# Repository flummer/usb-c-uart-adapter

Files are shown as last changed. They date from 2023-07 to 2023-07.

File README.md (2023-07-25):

# USB-C to TTL-Serial adapter with CP210x

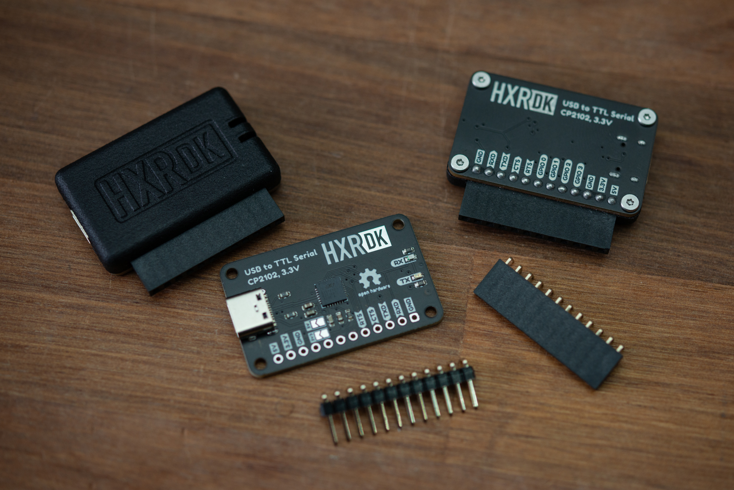
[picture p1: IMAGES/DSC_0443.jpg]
Adapters


This is just a simpel adapter with USB-C and TTL level UART, plus a few extra IO's. The pinout is designed to fit the 2022 Supercon/2023 Hackaday Berlin badges, and if you want to use the power rails, you need to bridge the corresponsing solder jumpers, they are disconneected by standard and need to be disconnected if used with the badges, as these to pins are used for other things on the badge.

## License

The contents of this repository is released under the following license:

* the "Creative Commons Attribution-ShareAlike 4.0 International License"
  (CC BY-SA 4.0) full text of this license is included in the LICENSE file
  and a copy can also be found at
  [http://creativecommons.org/licenses/by-sa/4.0/](http://creativecommons.org/licenses/by-sa/4.0/)

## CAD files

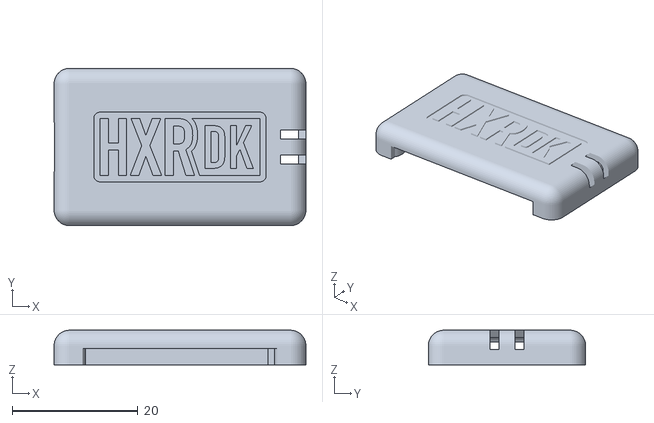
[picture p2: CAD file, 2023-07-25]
case/case.stl
40.0 x 25.0 x 5.50

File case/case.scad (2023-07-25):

/* Case for USB-C to TTL Serial Adapter
 *
 * Design: @thomasflummer
 *
 * License: CC-BY-SA
 *
 */

module case(pcb_length, pcb_width, height, corner_radius)
{
    union()
    {
        difference()
        {
            union()
            {
                hull()
                {
                    for (x = [-1, 1])
                    {
                        for (y = [-1, 1])
                        {
                            translate([x*(pcb_length/2 - corner_radius), y*(pcb_width/2 - corner_radius), (height - corner_radius)/2])
                                cylinder(h = height - corner_radius, r = corner_radius, center = true, $fn = 50);

                            translate([x*(pcb_length/2 - corner_radius), y*(pcb_width/2 - corner_radius), (height - corner_radius)])
                                sphere(r = corner_radius, $fn = 50);
                        }
                    }
                }
            }
            union()
            {
                // main cutout
                hull()
                {
                    for (x = [-1, 1])
                    {
                        for (y = [-1, 1])
                        {
                            translate([x*(pcb_length/2 - corner_radius), y*(pcb_width/2 - corner_radius), (height - corner_radius)/2])
                                cylinder(h = height - corner_radius + 0.01, r = corner_radius - 1.2, center = true, $fn = 50);

                            translate([x*(pcb_length/2 - corner_radius), y*(pcb_width/2 - corner_radius), (height - corner_radius)])
                                sphere(r = corner_radius - 1.2, $fn = 50);
                        }
                    }
                }

                // USB connector cutout
                translate([-pcb_length/2, 0, 3.6/2])
                rotate(90, [0, 0, 1])
                rotate(90, [1, 0, 0])
                    hull()
                    {
                        for (x = [-1, 1])
                        {
                            for (y = [-1, 1])
                            {
                                translate([x*(9.4/2 - 1.5), y*(3.6/2 - 1.5), 0])
                                    cylinder(h = 10, r = 1.5, center = true, $fn = 50);
                            }
                        }
                    }

                translate([-pcb_length/2+10/2-0.2, 0, 0])
                    cube([10, 9.4, 3.6], center = true);

                // Activity LEDs
                
                translate([pcb_length/2-6, 2, 0])
                rotate(45, [0, 1, 0])
                    cube([5, 1.4, 20], center = true);

                translate([pcb_length/2-6, -2, 0])
                rotate(45, [0, 1, 0])
                    cube([5, 1.4, 20], center = true);

                // 12 pin female header
                translate([0, -pcb_width/2, 2.54/2])
                    cube([12*2.54+0.4, 5, 2.54+0.1], center = true);
                
                    
                // logo on the inside (for clear transparent)
                // translate([0, 0, height-3.3])
                // logo on the outside (for non-clear)
                translate([0, 0, height+2.5-0.3])
                linear_extrude(height = 5, center = true, scale=1)
                    import(file = "logo_simple.svg", center = true, dpi = 200);

                for (x = [-1, 1])
                {
                    for (y = [-1, 1])
                    {
                        translate([x*((pcb_length)/2 - corner_radius), y*((pcb_width)/2 - corner_radius), (height-1.2)/2])
                            cylinder(h = height-1.2, r = 1.5, center = true, $fn = 50);
                    }
                }
            }
        }
        difference()
        {
            intersection()
            {
                union()
                {
                    // main cutout
                    hull()
                    {
                        for (x = [-1, 1])
                        {
                            for (y = [-1, 1])
                            {
                                translate([x*(pcb_length/2 - corner_radius), y*(pcb_width/2 - corner_radius), (height - corner_radius)/2])
                                    cylinder(h = height - corner_radius + 0.01, r = corner_radius - 1, center = true, $fn = 50);

                                translate([x*(pcb_length/2 - corner_radius), y*(pcb_width/2 - corner_radius), (height - corner_radius)])
                                    sphere(r = corner_radius - 1, $fn = 50);
                            }
                        }
                    }
                }
                union()
                {
                    for (x = [-1, 1])
                    {
                        for (y = [-1, 1])
                        {
                            translate([x*((pcb_length)/2 - corner_radius), y*((pcb_width)/2 - corner_radius), (height)/2])
                                cylinder(h = height, r = corner_radius, center = true, $fn = 50);
                        }
                    }
                    
                    translate([pcb_length/2-6/2, 0, height/2])
                        cube([6, 1.2, height], center = true);
                }
            }
            union()
            {
                for (x = [-1, 1])
                {
                    for (y = [-1, 1])
                    {
                        translate([x*((pcb_length)/2 - corner_radius), y*((pcb_width)/2 - corner_radius), (height - 1.2)/2])
                            cylinder(h = height - 1.2 + 0.01, r = 1.5, center = true, $fn = 50);
                    }
                }
            }
        }
    }
}

module light_guide()
{
    difference()
    {
        union()
        {
            translate([-2.5, 0, -2.5])
            rotate(90, [1, 0, 0])
                cylinder(h = 2.5, r = 2.5, center = true, $fn = 50);
            
            translate([-2.5 - 2.5/2, 0, -2.5])
                cube([2.5, 2.5, 5], center = true);

            translate([-2.5, 0, -2.5 - 2.5/2])
                cube([5, 2.5, 2.5], center = true);
        }
        union()
        {
            translate([-2.5, 0, -2.5*2 - 3/2 + 0.8])
                cube([5.01, 2.51, 3], center = true);

            difference()
            {
                union()
                {
                    translate([-2.5, 0, -2.5])
                        cube([6, 6, 6], center = true);
                }
                union()
                {
                    translate([-2.5, 0, -2.5])
                    rotate(90, [1, 0, 0])
                        cylinder(h = 7, r = 2.5 - 1.2, center = true, $fn = 50);
                    
                    translate([-2.5 - 3/2, 0, -2.5-1.2])
                        cube([3, 2.5, 5], center = true);

                    translate([-2.5-1.2, 0, -2.5 - 3/2])
                        cube([5, 2.5, 3], center = true);                

                    translate([-6, 0, -5.5])
                    rotate(45, [0, 1, 0])
                        cube([5-0.2, 1.4-0.2, 20], center = true);
                
                }
            }
        }        
    }
}

case(40, 25, 5.5, 2.5);

//light_guide();

/*
translate([40/2, 2, 5.5])
    color("#eeeeee")
    light_guide();

translate([40/2, -2, 5.5])
    color("#eeeeee")
    light_guide();
*/

/*
difference()
{
    case(40, 25, 5.5, 2.5);
    translate([0, -25-(25/2)+2.5, 0])
        cube([50, 50, 50], center = true);
}
*/

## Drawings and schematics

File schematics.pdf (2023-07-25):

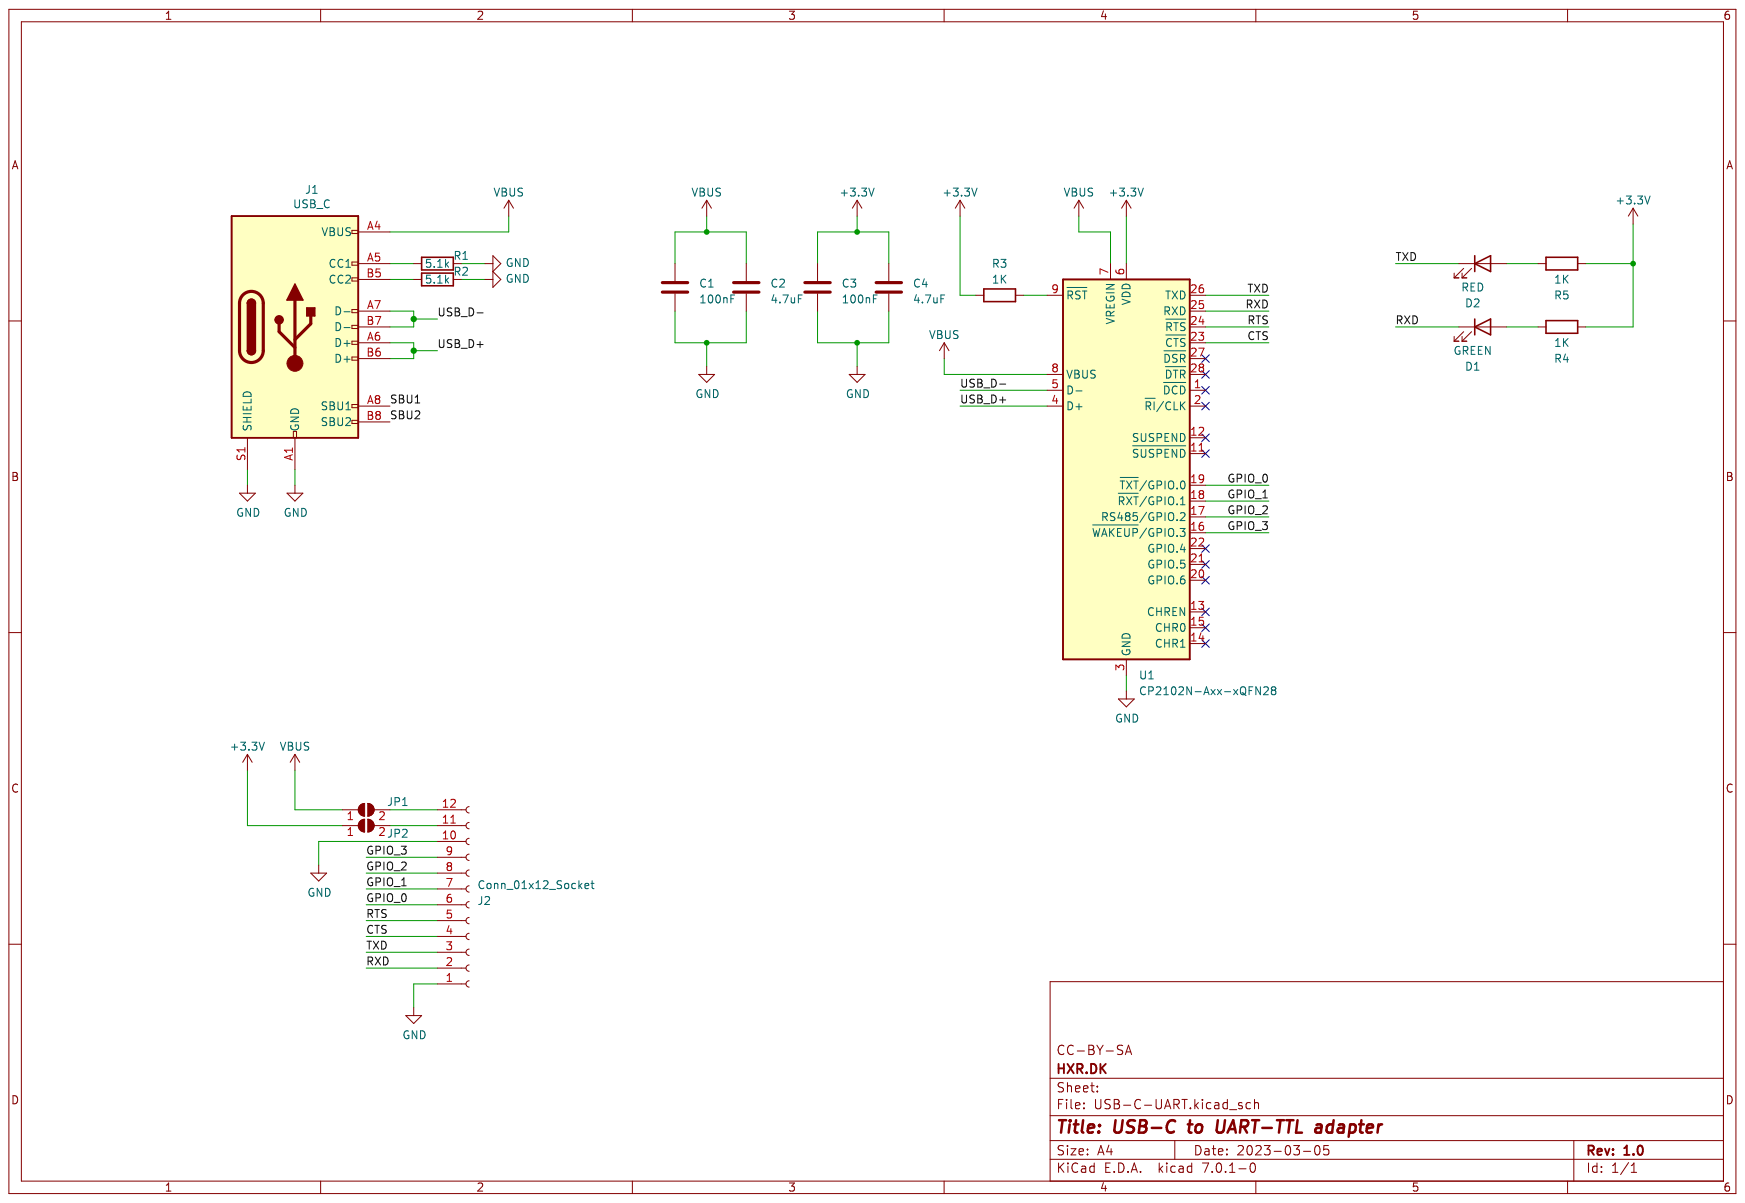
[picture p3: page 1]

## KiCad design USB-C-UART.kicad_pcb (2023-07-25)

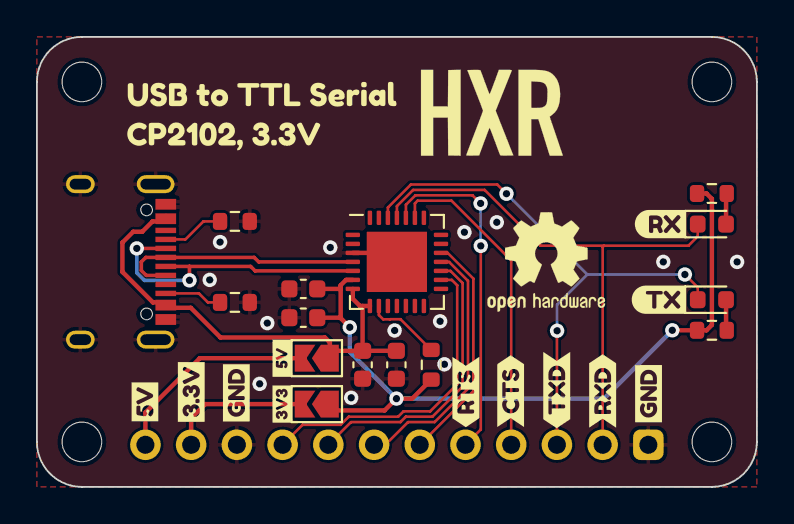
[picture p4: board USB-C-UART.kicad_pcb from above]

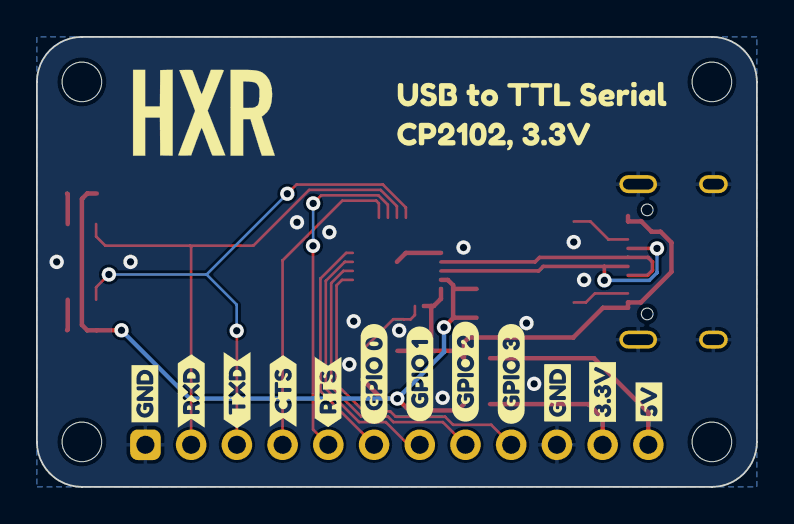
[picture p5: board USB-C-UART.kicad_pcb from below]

Board: 2 copper layers, 40.0 x 25.0 mm, 42 parts (14 on the bottom side), 20 nets.

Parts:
C1, C3: 100nF; C_0603_1608Metric
C2, C4: 4.7uF; C_0603_1608Metric
D1: GREEN; LED_0603_1608Metric
D2: RED; LED_0603_1608Metric
J1: USB_C; USB_C_Receptacle_XKB_U262-16XN-4BVC11
J2: Conn_01x12_Socket; PinSocket_1x12_P2.54mm_Horizontal
JP1, JP2: SolderJumper_2_Open; SolderJumper-2_P1.3mm_Open_TrianglePad1.0x1.5mm
R1, R2: 5.1k; R_0603_1608Metric
R3, R4, R5: 1K; R_0603_1608Metric
U1: CP2102N-Axx-xQFN28; QFN-28-1EP_5x5mm_P0.5mm_EP3.35x3.35mm
kibuzzard-6403CC6D: G***; kibuzzard-6403CC6D
kibuzzard-6403CC56: G***; kibuzzard-6403CC56
kibuzzard-6403D5C9: G***; kibuzzard-6403D5C9
kibuzzard-6403D576: G***; kibuzzard-6403D576
kibuzzard-6403DA4F: G***; kibuzzard-6403DA4F
kibuzzard-6403DA5C: G***; kibuzzard-6403DA5C
kibuzzard-6403DA6F: G***; kibuzzard-6403DA6F
kibuzzard-6403DA7C: G***; kibuzzard-6403DA7C
kibuzzard-6403DA55: G***; kibuzzard-6403DA55
kibuzzard-6403DA63: G***; kibuzzard-6403DA63
kibuzzard-6403DA69: G***; kibuzzard-6403DA69
kibuzzard-6403DAA1: G***; kibuzzard-6403DAA1
kibuzzard-6403DAA7: G***; kibuzzard-6403DAA7
kibuzzard-6403DAAD: G***; kibuzzard-6403DAAD
kibuzzard-6403DAB7: G***; kibuzzard-6403DAB7
kibuzzard-6403DABE: G***; kibuzzard-6403DABE
kibuzzard-6403DAC4: G***; kibuzzard-6403DAC4
kibuzzard-6403DAD1: G***; kibuzzard-6403DAD1
kibuzzard-6403EE79: G***; kibuzzard-6403EE79
kibuzzard-6403EEC8: G***; kibuzzard-6403EEC8
kibuzzard-6404B363, kibuzzard-6404B363#2: G***; kibuzzard-6404B363
kibuzzard-6404F9C3: G***; kibuzzard-6404F9C3
kibuzzard-6404F9EF: G***; kibuzzard-6404F9EF
kibuzzard-6404F9F6: G***; kibuzzard-6404F9F6
kibuzzard-6404FA02: G***; kibuzzard-6404FA02

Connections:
+3.3V: C3.1, C4.1, JP2.1 (A), R3.1, R4.1, R5.1, U1.6 (VDD)
/CTS: J2.4, U1.23 (~CTS)
/GPIO_0: J2.6, U1.19 (~TXT/GPIO.0)
/GPIO_1: J2.7, U1.18 (~RXT/GPIO.1)
/GPIO_2: J2.8, U1.17 (RS485/GPIO.2)
/GPIO_3: J2.9, U1.16 (~WAKEUP/GPIO.3)
/RTS: J2.5, U1.24 (~RTS)
/RXD: D1.1 (K), J2.2, U1.25 (RXD)
/TXD: D2.1 (K), J2.3, U1.26 (TXD)
/USB_D+: J1.A6 (D+), J1.B6 (D+), U1.4 (D+)
/USB_D-: J1.A7 (D-), J1.B7 (D-), U1.5 (D-)
GND: C1.2, C2.2, C3.2, C4.2, J1.A1 (GND), J1.A12 (GND), J1.B1 (GND), J1.B12 (GND), J1.S1 (SHIELD), J2.1, J2.10, R1.1, R2.1, U1.3 (GND), U1.29 (GND)
unnamed: D1.2 (A), R4.2
unnamed: D2.2 (A), R5.2
unnamed: J1.A5 (CC1), R1.2
unnamed: J1.B5 (CC2), R2.2
unnamed: J2.11, JP2.2 (B)
unnamed: J2.12, JP1.2 (B)
unnamed: R3.2, U1.9 (~RST)
VBUS: C1.1, C2.1, J1.A4 (VBUS), J1.A9 (VBUS), J1.B4 (VBUS), J1.B9 (VBUS), JP1.1 (A), U1.7 (VREGIN), U1.8 (VBUS)
